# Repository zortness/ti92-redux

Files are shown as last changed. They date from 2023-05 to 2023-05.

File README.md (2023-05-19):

# TI-92 Redux
Bringing the TI-92's back to life.

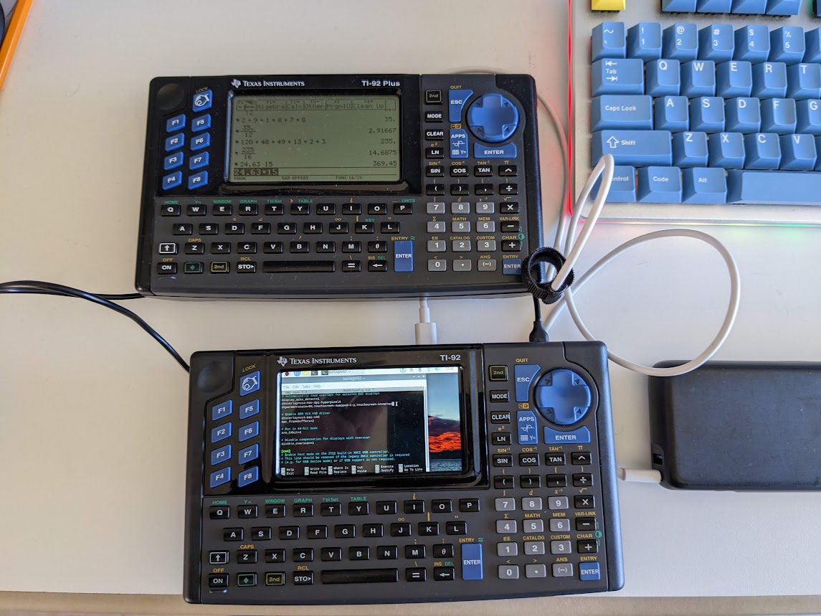
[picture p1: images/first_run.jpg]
First Run


## Intro
My first graphing calculator and introduction to portable programming was an early TI-85.
I became enamoured with the TI calculators in the 90s, longing for a TI-92 when they were
announced, but never able to purchase one. Now, you can find them in various conditions for
relatively cheap on the internet.

Unfortunately, the most common issues seem to be screen related, and the screens on the TI-92
are not easily repaired. Such was the case with one of the TI-92s I purchased, so I began 
thinking about how I could make use of this iconic chasis. 

I found other projects, notably one seen on Hackaday, the 
[TI-92 Revive project](https://hackaday.io/project/175448-reviving-the-ti-92-calculator-into-a-rpi-pc)
and corresponding [github repo](https://github.com/ccadic/TI92-revive). 
This is a cool project in a similar vein, but I wanted to make some different design decisions.

* First, I wanted the PCB to be as simple as possible for the first attempt, trying to keep to a 
2-layer board. 
* Second, I wanted to have the keyboard to be operable as a standalone unit, in case someone wanted
to use it on another project or different SBC than I chose.
* Third, I wanted to re-use as much of the original TI-92 chasis as possible. A goal which I didn't
meet to the original expectation due to the complexity of the original back plates. 

## Physical Replication Strategy
For several parts of this build, I traced the original components (PCB, back plate, etc) onto a 
piece of paper, then scanned them with a flat bed scanner. I then took the drawings and traced 
them into SVG's set to the correct dimensions using InkScape so I could use them with other tools 
such as KiCad and OpenSCAD. I also printed multiple versions of the PCB and various chasis bits 
on my 3D printer to work toward getting the correct fitment with the original chasis pieces.

Most of the SVGs and drawings are included [here](drawings/).

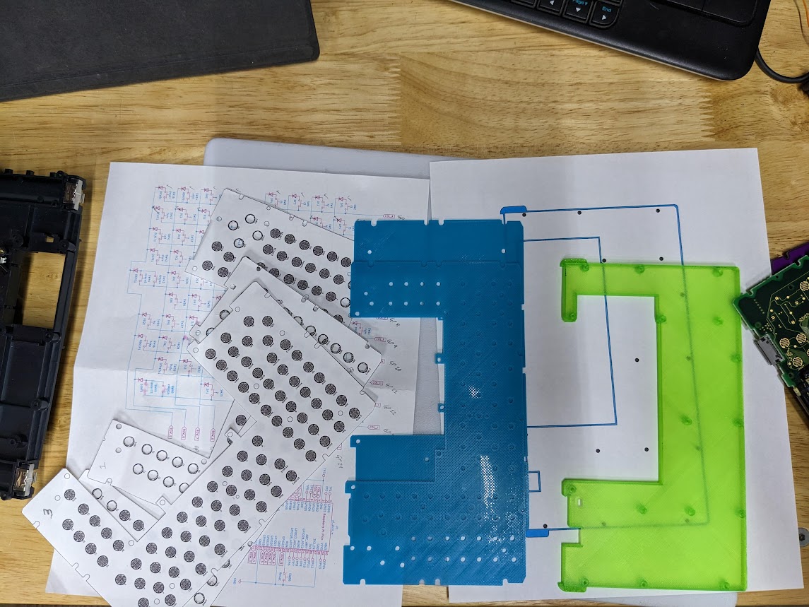
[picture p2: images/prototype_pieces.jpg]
prototypes


## PCB Design
The PCB is designed in KiCad 7. The board is designed as a custom keyboard, using a Pi Pico (or Pico W)
as the keybord controller. The routing is all done by hand with an attempt at keeping the jumps minimal.

Note: The PCB has tabs and holes to hold an SBC that lines up with the Raspberry Pi mounting holes.

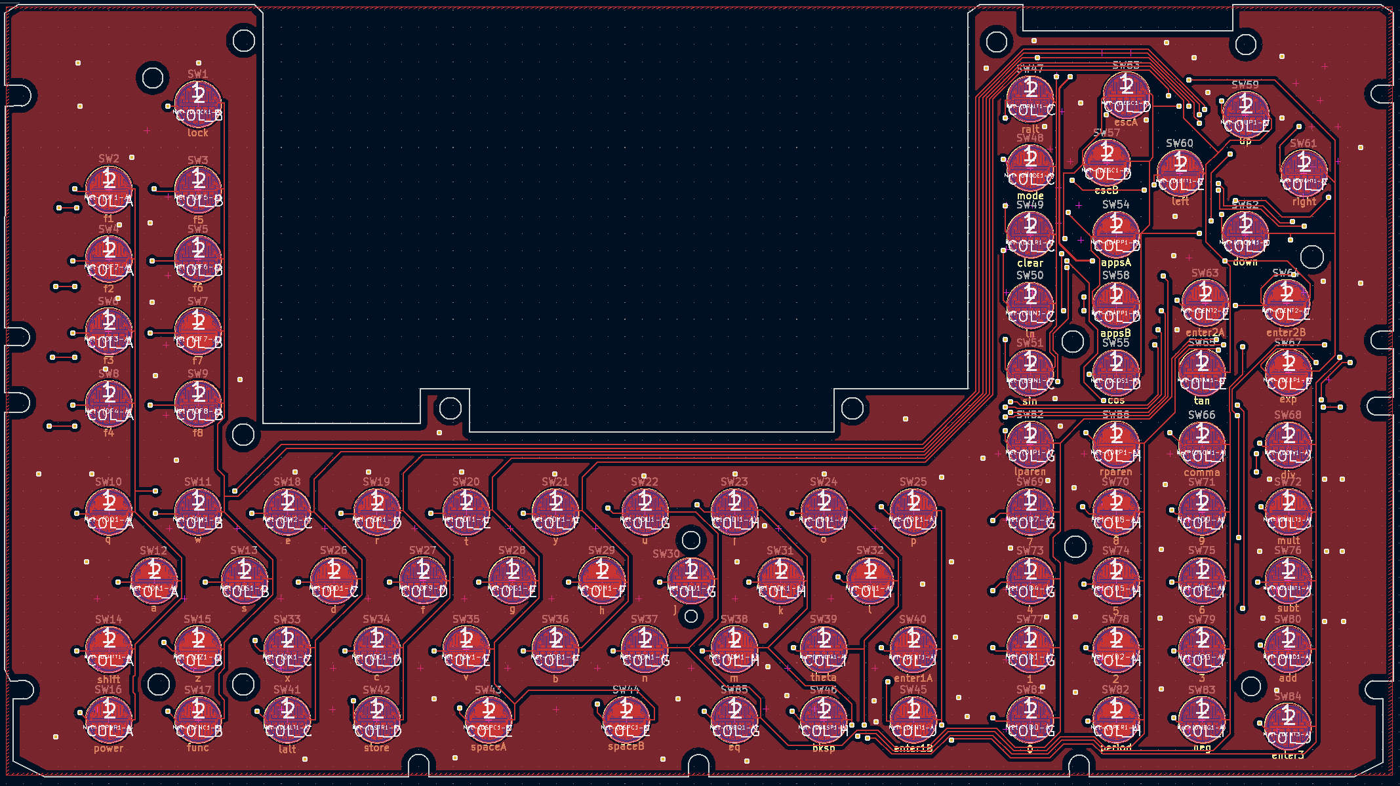
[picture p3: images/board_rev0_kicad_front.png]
Front

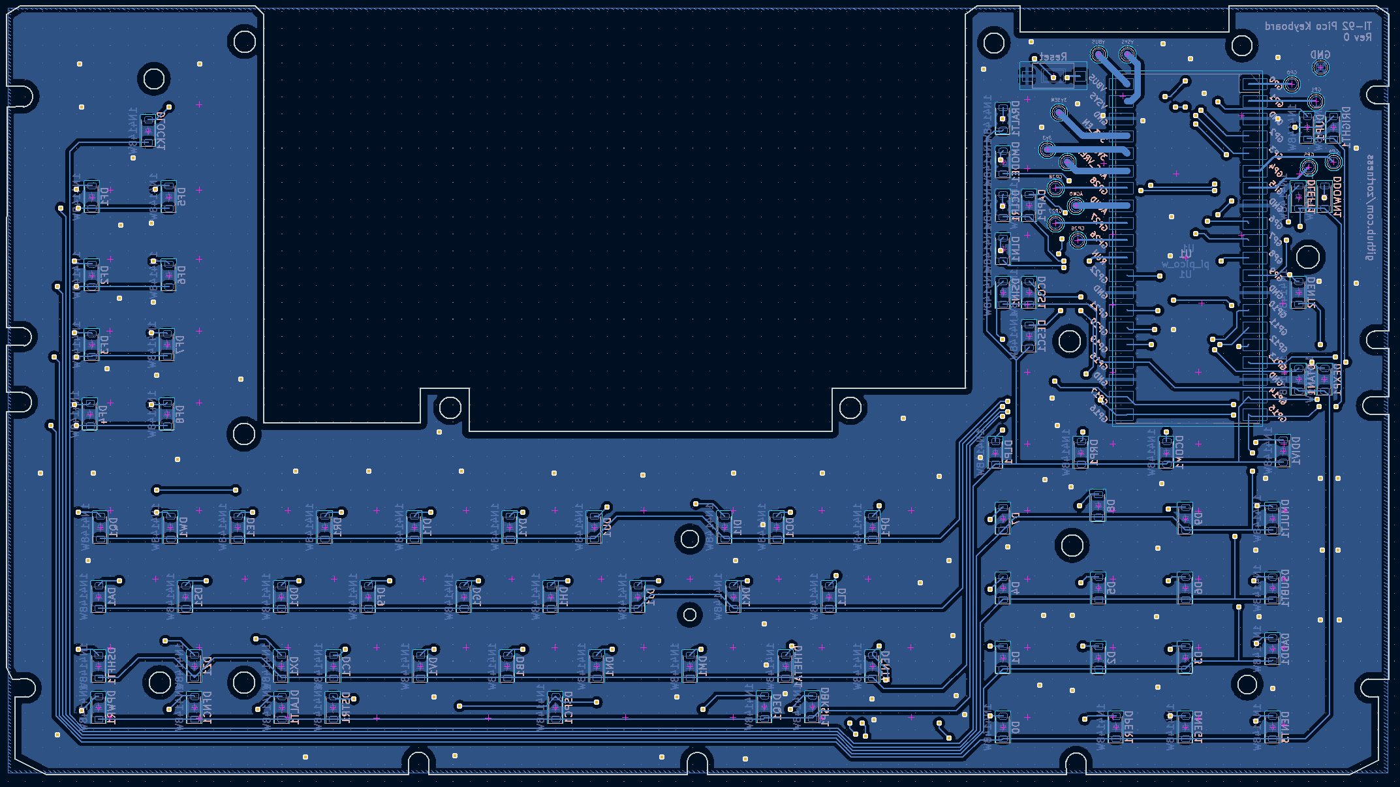
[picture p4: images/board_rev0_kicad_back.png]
Back

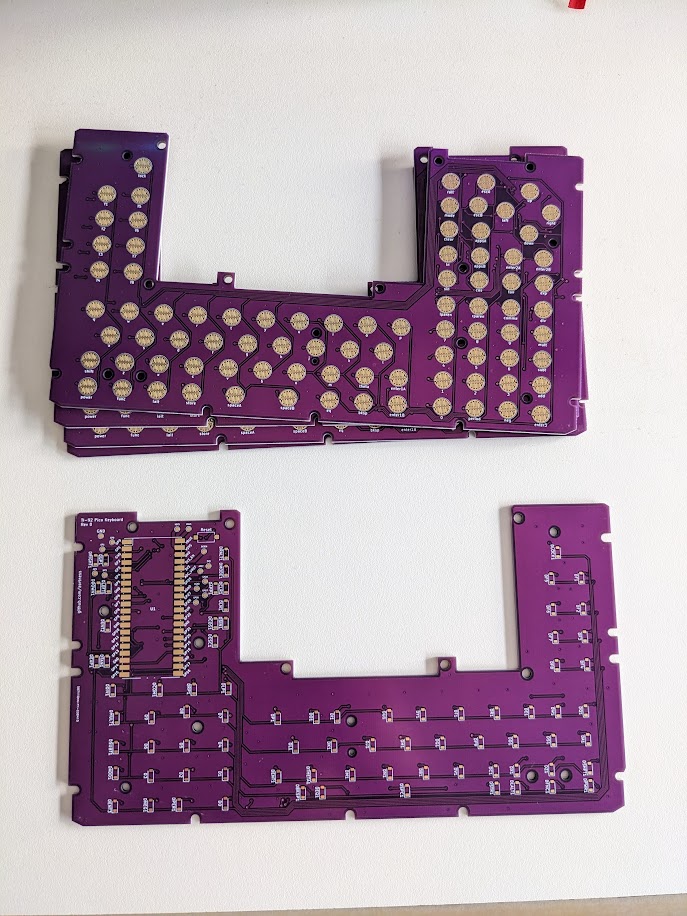
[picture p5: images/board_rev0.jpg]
Manufactured


### BOM And Assembly
* 80 count SOD-123 general purpose diode, [1N4148W-TP](https://www.digikey.com/en/products/detail/micro-commercial-co/1N4148W-TP/717196)
* 1 count [RS-282G05A3 tactile switch](https://www.digikey.com/en/products/detail/c-k/RS-282G05A3-SM-RT/2747190)
* 1 count [Pi Pico W](https://www.digikey.com/en/products/detail/raspberry-pi/SC0918/16608263)

I was able to solder all of this with a relatively large soldering iron and some tweezers.
Tin one of the pads for the component first, then heat it up again and set the part on the pad.
Only solder the second pad when you're happy with the alignment.

I used a Raspberry Pi 4 as my SBC.

To pair with the Pi 4, I used the [Pimoroni Hyperpixel 4.0" Touch Display](https://www.adafruit.com/product/3578).
This display is pretty expensive, but I purchased this a while ago, and noticing it seemed to fit perfectly
into the TI-92 chasis is one of the factors that pushed me into completing this project.

A 4" screen of this ratio fits almost perfectly into the TI-92. 

## Printed Pieces
I used OpenSCAD to assemble the designs for printing. Most of the prints are derived from one or 
more SVG drawings, the back plate being the most complicated.

During development, I dropped my keyboard and had to chase keys across the house multiple times. 
I ultimately ended up finding all of my keys, but there is a basic key file included in case you
need to print one.

## Keyboard Software
I chose the [KMK firmware](https://github.com/KMKfw/kmk_firmware) 
(as opposed to something like [QMK](https://docs.qmk.fm/#/) ) mostly due to ease of use and direct
support for the Pi Pico and Pico W. This has the added bonus of being able to easily reprogram the 
keyboard from the finished device itself, using the keyboard itself to make changes.

Follow the instructions for installing the KMK firmware on the device (basically copy most of the
files included in their release). Then drag and drop the [firmware/code.py](firmware/code.py) file
onto the device and it should be ready to go.

## Power Supply
There is no power supply built into this project. For my personal prototype, I'm using a 
[2x18650 container](https://www.digikey.com/en/products/detail/seeed-technology-co-ltd/114090053/10451921)
with a built-in on/off switch into a cheap buck converter. I also attempted to use a L7805 5V
linear regulator, and while it works, even with a heat sink it will get very hot.

I am currently powering the Pi Pico W through the USB cable that connects it to the Pi 4. 

## Development Software
* [KiCad 7](https://www.kicad.org/)
* [InkScape 1.2](https://inkscape.org/)
* [OpenSCAD](http://openscad.org/)
* [KMK Firmware](https://github.com/KMKfw/kmk_firmware)

## Version History

### 2023-05-19 Rev 0
* PCB Rev 0 - Functional 
  * Some mounting hole misalignments that need to be fixed by hand
* KMK Keyboard Firmware - Functional
  * Will work as a USB keyboard on any modern PC
  * Some QoL improvements need to be made on the mouse functionality
  * Really need BlueTooth support to eliminate the USB cable
* Back Plate - Functional
  * Very basic, you can tape or glue power sources to it if so inclined

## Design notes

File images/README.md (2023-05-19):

# TI-92 Redux Images

## Prototype Pieces
prototypes

## PCB Design
Front
Back

## Rev0 PCBs
Manufactured
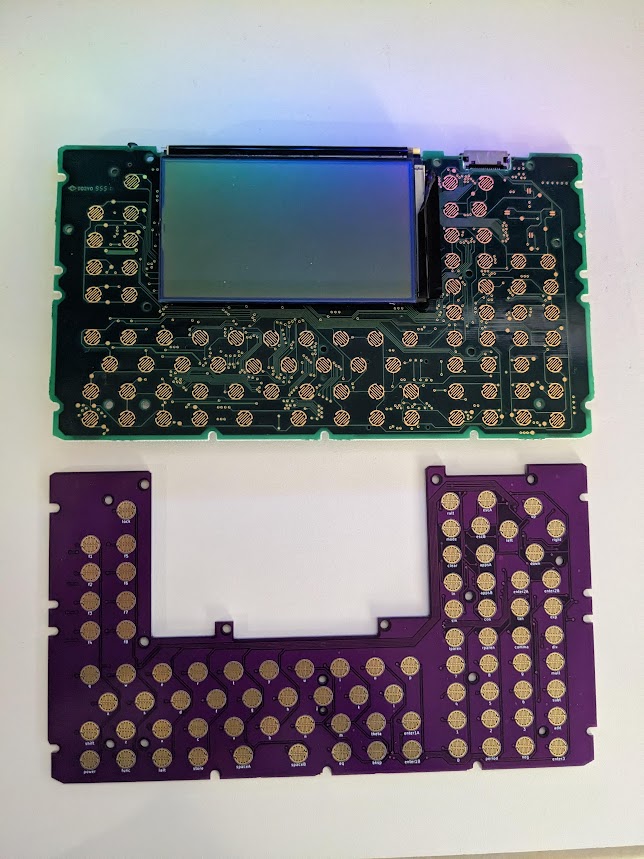
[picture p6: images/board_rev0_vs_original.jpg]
Manufactured vs Original

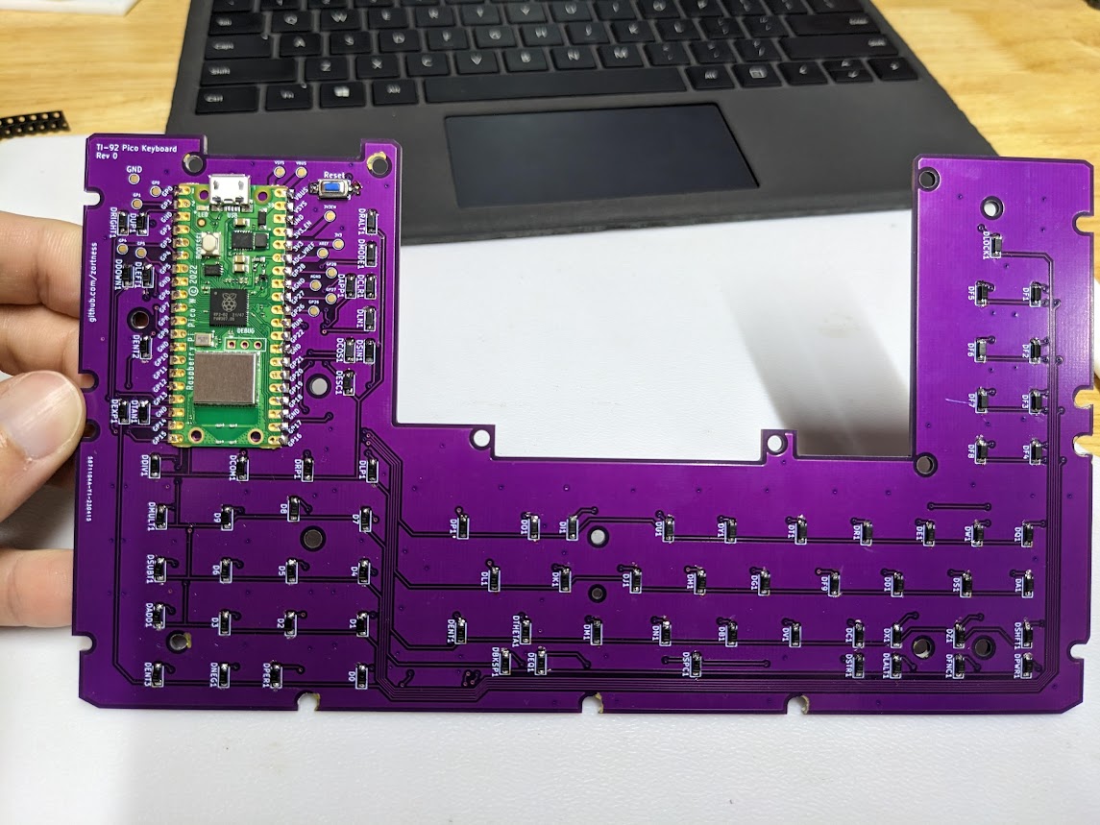
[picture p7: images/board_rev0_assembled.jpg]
Assembled


## Working!
First Run
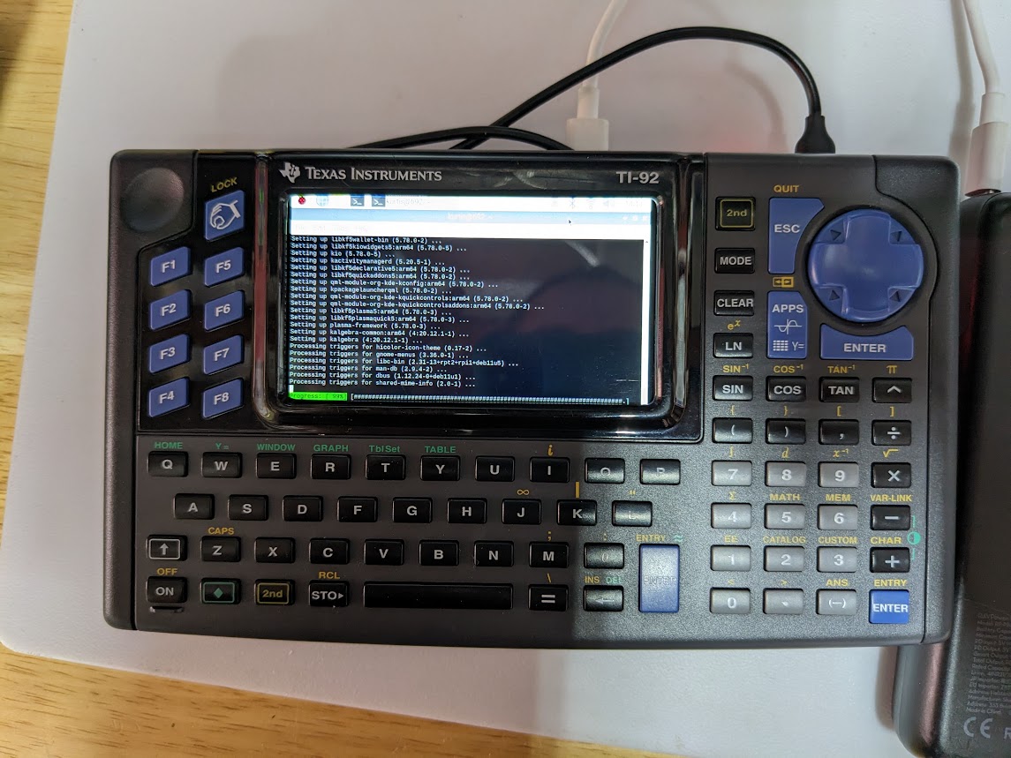
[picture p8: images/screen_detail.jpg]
Screen Detail

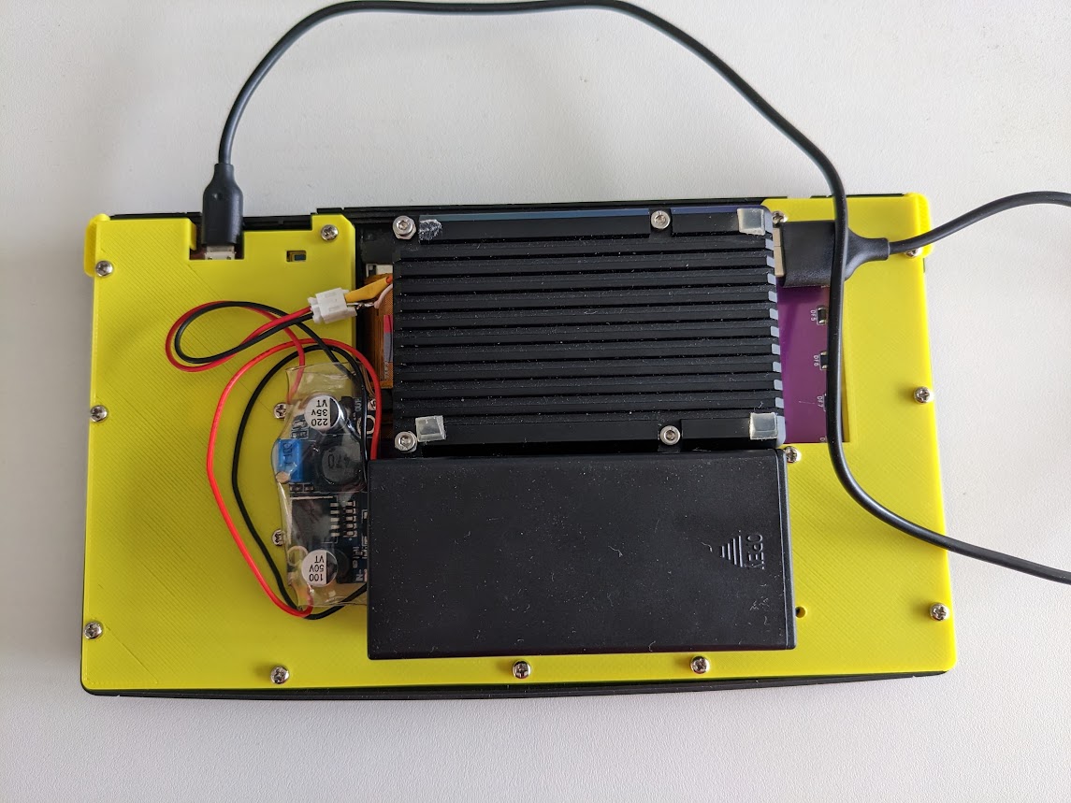
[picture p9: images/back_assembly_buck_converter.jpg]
Back Assembly


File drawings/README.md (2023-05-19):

# TI-92 Redux Drawings

I recommend using [InkScape](https://inkscape.org/) to view or modify these drawings.
Most of these were made directly with InkScape or exported from KiCad.

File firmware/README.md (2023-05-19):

# TI-92 Redux Keyboard Firmware

This firmware is based on the [KMK firmware](https://github.com/KMKfw/kmk_firmware).

Follow their instructions to install the KMK framework onto your Pi Pico or Pi Pico W,
then copy over the `code.py` file included here.

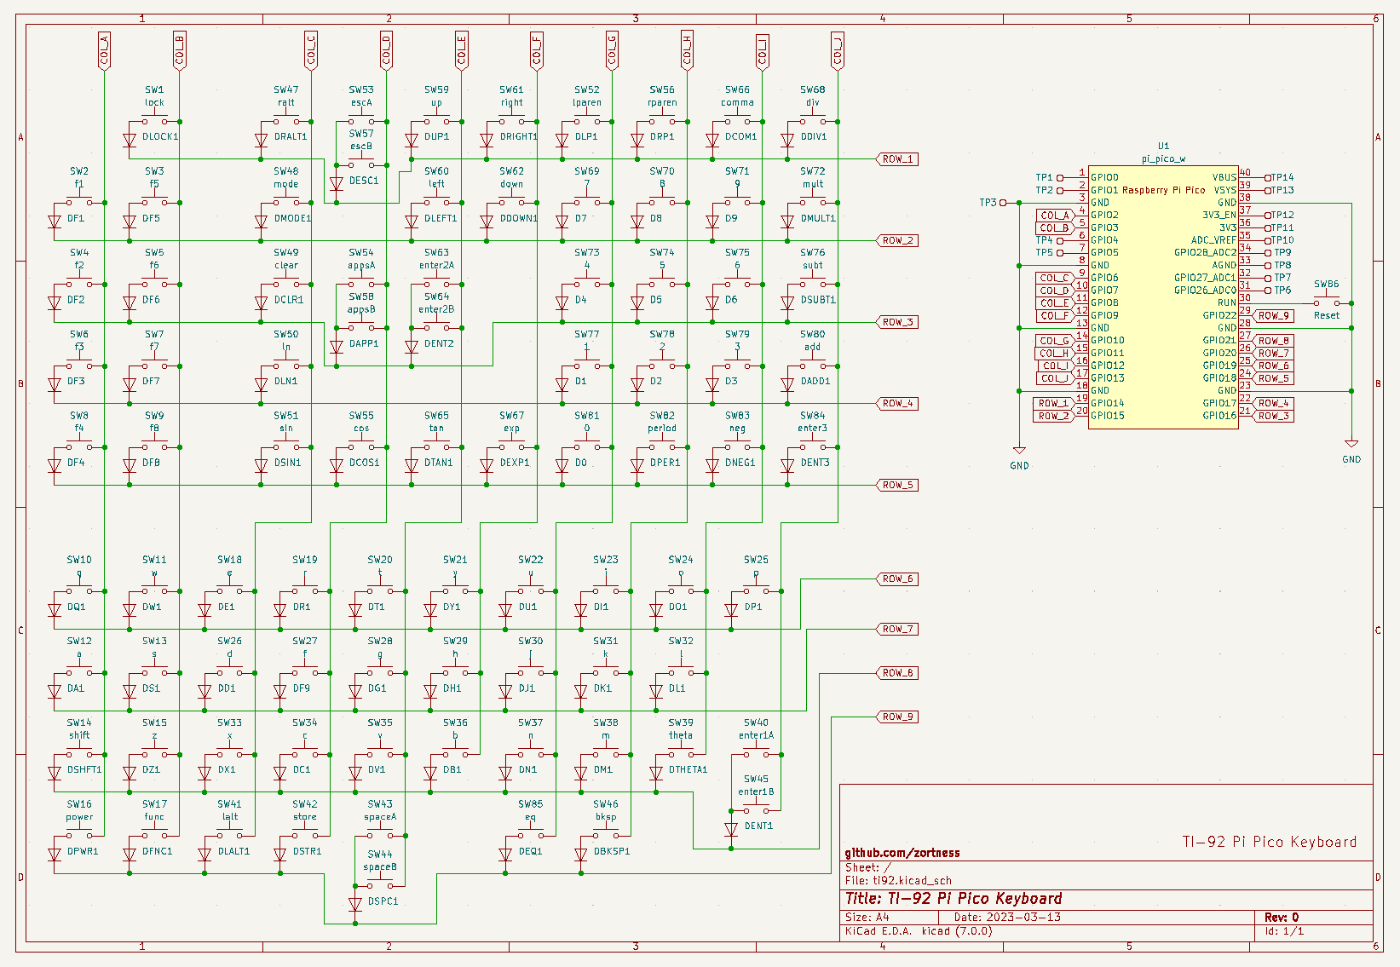
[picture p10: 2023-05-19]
images/board_rev0_kicad_schematic.png

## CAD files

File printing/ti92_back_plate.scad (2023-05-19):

$fn=96;


/**
* In newer releases of OpenSCAD we'll be able to specify
* layers that we want to import [feature added in 2022]
* import("ti92_back_drawing.svg", id="main_fill")
* id="outline"
* id="hole_casters"
* id="holes"
* But for now, we have each layer as its own file.
*/

height=5;
back_thickness=.6;
tab_thickness=3;

difference() {
    union() {
        translate([0,0,(height-back_thickness)])
        linear_extrude(back_thickness)
        import("../drawings/ti92_back_drawing.svg");
        
        linear_extrude(height)
        import("../drawings/ti92_back_drawing_outline.svg");
        
        linear_extrude(height)
        import("../drawings/ti92_back_drawing_hole_casters.svg");
    }
    
    
    // cut the holes
    translate([0,0,-0.01])
    linear_extrude(height+0.1)
    import("../drawings/ti92_back_drawing_holes.svg");
    
    // cut the USB cable slot
    #translate([54, 79, -0.01])
    linear_extrude(height-back_thickness)
    square([6,18]);
    
    // cut the reset button hole
    #translate([56, 105, 0])
    linear_extrude(height+0.1)
    square([3,5]);
    
    // cut the excess of the tabs
    #translate([43,52.9,tab_thickness])
    linear_extrude(height)
    square([20,5]);
    #translate([44.5,57,tab_thickness])
    linear_extrude(height)
    square([3,3]);
    
    #translate([43,260.8,tab_thickness])
    linear_extrude(height)
    square([20,5]);
    #translate([44.0,259,tab_thickness])
    linear_extrude(height)
    square([3,3]);
    
    // cut some diode interference holes where we took a chunk out for USB plugs on the right side
    #translate([62.5, 240, -0.01])
    linear_extrude(height/2)
    square([5,3]);
    
    #translate([106, 234, -0.01])
    linear_extrude(height/2)
    square([3,5]);
}

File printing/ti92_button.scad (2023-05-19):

$fn=96;



// base (mm)
baseWidth=10.54;
baseHeight=7.16;
baseDepth=2.08;

module baseChunk() {
    // this is naturally a top-right
    linear_extrude(height=baseDepth, scale=0.95)
    square([baseWidth/2,baseHeight/2]);
}

module drawBase() {
    // top right
    baseChunk();
    // top left
    mirror([1,0,0]) baseChunk();
    // bottom right
    mirror([0,1,0]) baseChunk();
    // bottom left
    rotate([0,0,180]) baseChunk();
}

drawBase();

upperWidth=9.22;
upperHeight=5.78;
upperDepth=4.90;

module upperChunk() {
    translate([0,0,baseDepth])
    linear_extrude(height=upperDepth, scale=0.95)
    square([upperWidth/2,upperHeight/2]);
}

module drawUpper() {
    // top right
    upperChunk();
    // top left
    mirror([1,0,0]) upperChunk();
    // bottom right
    mirror([0,1,0]) upperChunk();
    // bottom left
    rotate([0,0,180]) upperChunk();
}

drawUpper();

/*radius=5;
rotate([0,90,0])
translate([-radius,0,0])
linear_extrude(20)
circle(radius);
*/

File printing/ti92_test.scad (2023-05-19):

$fn=96;

difference() {
    
    // base rectangle
    translate([0,0,0.01])
    linear_extrude(0.6)
    square([202,112]);

    // cut away the edge layer
    linear_extrude(1)
    import("../drawings/ti92-brd.svg");

    // remove screen island
    translate([38.1,56.5,-0.01])
    linear_extrude(1.01)
    square([102,65]);
    
    translate([38.1,51.5,-0.01])
    linear_extrude(1.01)
    square([22.5,6]);
    
    translate([68,50,-0.01])
    linear_extrude(1.01)
    square([52.5,8]);
    
    //#translate([126.5,52.5,-0.01])
    //linear_extrude(1.01)
    //square([13.5,5]);
    
    // remove other little island
    translate([148.1,108.5,-0.01])
    linear_extrude(1.01)
    square([30.5,5]);
    
    // ** OUTER SCREWS **
    // LEFT EDGE
    /*
    #translate([2.5,12.8,-0.01])
    linear_extrude(1.01)
    circle(1.2);
    
    #translate([2.5,54.5,-0.01])
    linear_extrude(1.01)
    circle(1.2);
    
    #translate([2.5,64.1,-0.01])
    linear_extrude(1.01)
    circle(1.2);
    
    #translate([2.5,99.2,-0.01])
    linear_extrude(1.01)
    circle(1.2);
    
    // LOWER EDGE
    #translate([59,2,-0.01])
    linear_extrude(1.01)
    circle(1.2);
    
    #translate([100,2,-0.01])
    linear_extrude(1.01)
    circle(1.2);
    
    #translate([155.1,2,-0.01])
    linear_extrude(1.01)
    circle(1.2);
    */
}

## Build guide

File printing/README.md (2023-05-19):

# TI-92 Redux 3D Printing Files

These files require [OpenSCAD](http://openscad.org/).

I printed these files with an Ender 3 using PLA.

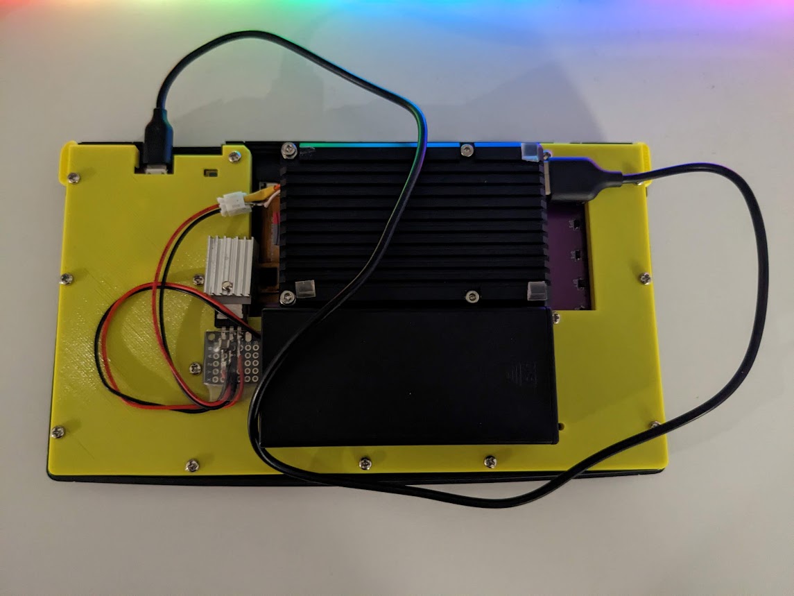
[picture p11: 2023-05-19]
images/back_assembly_linear_regulator.jpg

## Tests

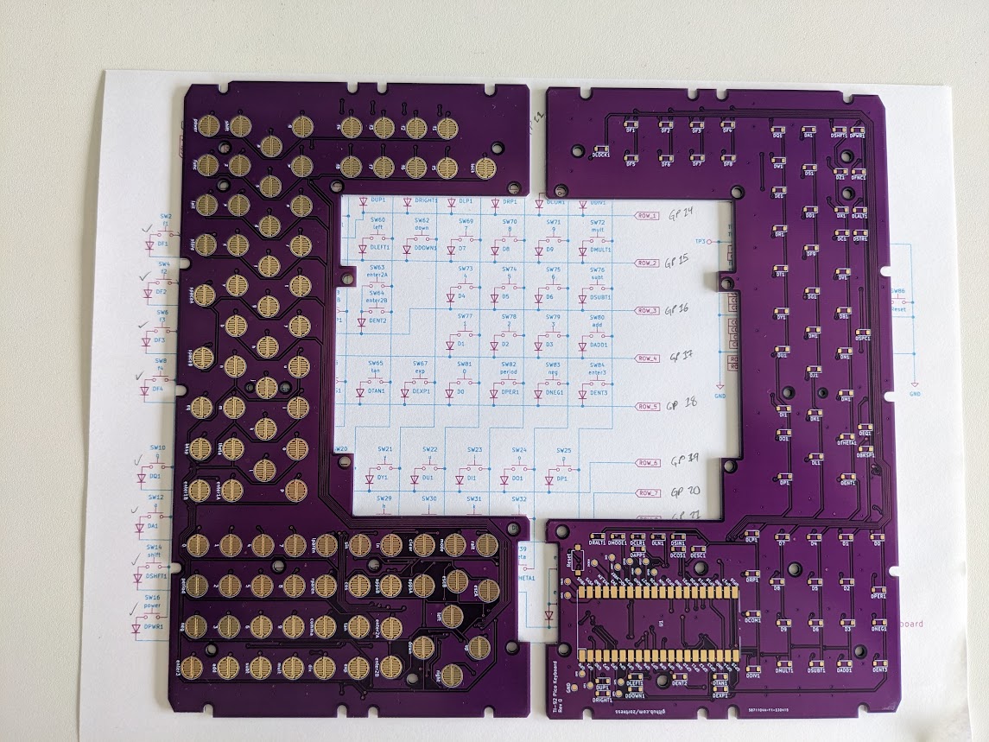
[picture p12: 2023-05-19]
images/board_rev0_pinout_testing.jpg

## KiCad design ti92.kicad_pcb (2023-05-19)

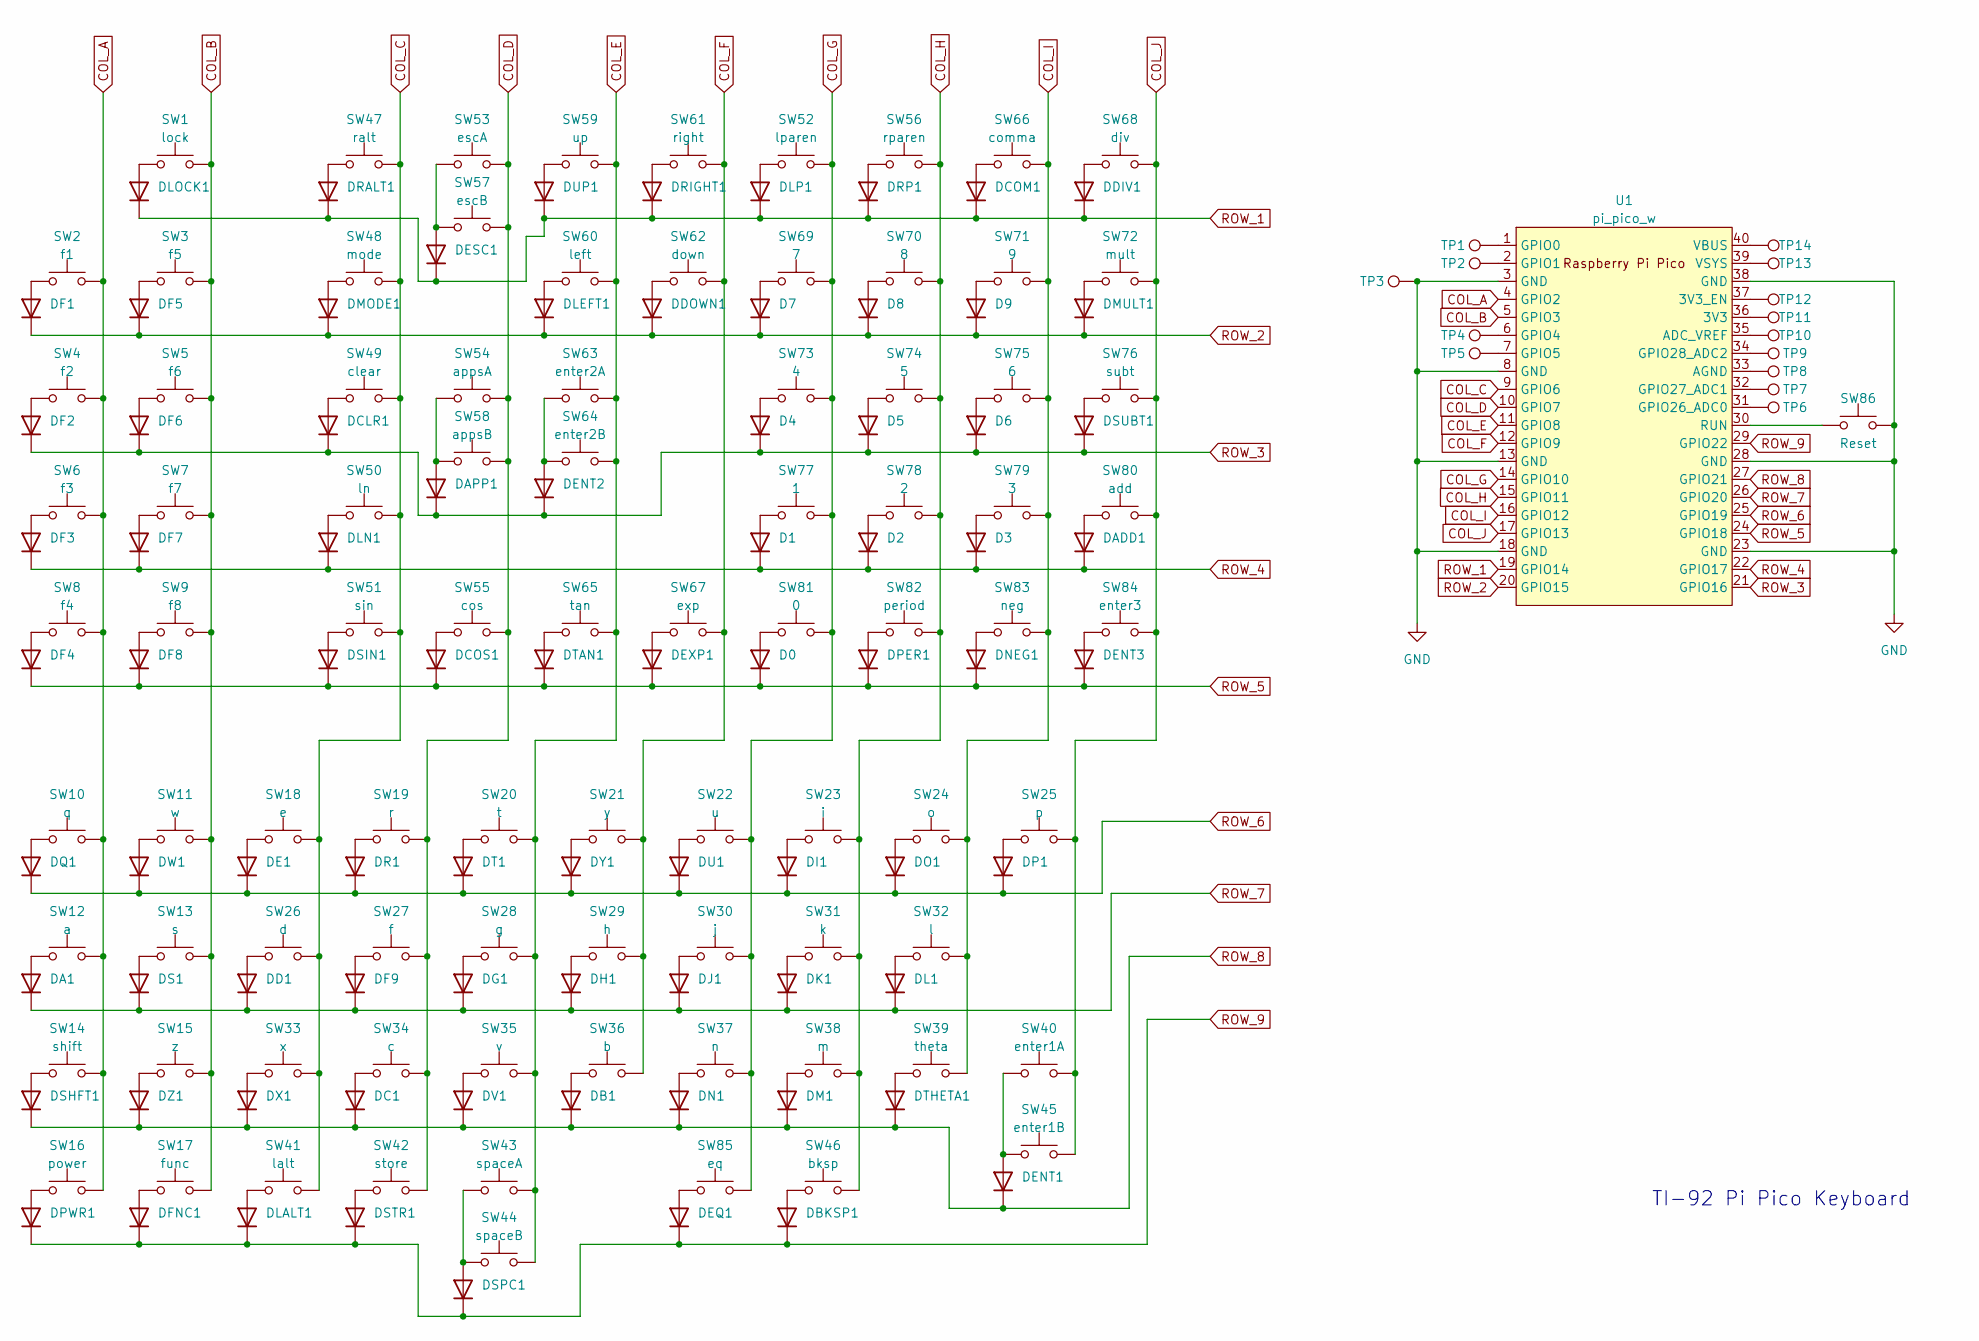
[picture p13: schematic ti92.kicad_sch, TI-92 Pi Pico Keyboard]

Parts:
D0, D1, D2, D3, D4, D5, D6, D7, D8, D9: 1N4148W; D_SOD-123
DA1: 1N4148W; D_SOD-123
DADD1: 1N4148W; D_SOD-123
DAPP1: 1N4148W; D_SOD-123
DB1: 1N4148W; D_SOD-123
DBKSP1: 1N4148W; D_SOD-123
DC1: 1N4148W; D_SOD-123
DCLR1: 1N4148W; D_SOD-123
DCOM1: 1N4148W; D_SOD-123
DCOS1: 1N4148W; D_SOD-123
DD1: 1N4148W; D_SOD-123
DDIV1: 1N4148W; D_SOD-123
DDOWN1: 1N4148W; D_SOD-123
DE1: 1N4148W; D_SOD-123
DENT1, DENT2, DENT3: 1N4148W; D_SOD-123
DEQ1: 1N4148W; D_SOD-123
DESC1: 1N4148W; D_SOD-123
DEXP1: 1N4148W; D_SOD-123
DF1, DF2, DF3, DF4, DF5, DF6, DF7, DF8, DF9: 1N4148W; D_SOD-123
DFNC1: 1N4148W; D_SOD-123
DG1: 1N4148W; D_SOD-123
DH1: 1N4148W; D_SOD-123
DI1: 1N4148W; D_SOD-123
DJ1: 1N4148W; D_SOD-123
DK1: 1N4148W; D_SOD-123
DL1: 1N4148W; D_SOD-123
DLALT1: 1N4148W; D_SOD-123
DLEFT1: 1N4148W; D_SOD-123
DLN1: 1N4148W; D_SOD-123
DLOCK1: 1N4148W; D_SOD-123
DLP1: 1N4148W; D_SOD-123
DM1: 1N4148W; D_SOD-123
DMODE1: 1N4148W; D_SOD-123
DMULT1: 1N4148W; D_SOD-123
DN1: 1N4148W; D_SOD-123
DNEG1: 1N4148W; D_SOD-123
DO1: 1N4148W; D_SOD-123
DP1: 1N4148W; D_SOD-123
DPER1: 1N4148W; D_SOD-123
DPWR1: 1N4148W; D_SOD-123
DQ1: 1N4148W; D_SOD-123
DR1: 1N4148W; D_SOD-123
DRALT1: 1N4148W; D_SOD-123
DRIGHT1: 1N4148W; D_SOD-123
DRP1: 1N4148W; D_SOD-123
DS1: 1N4148W; D_SOD-123
DSHFT1: 1N4148W; D_SOD-123
DSIN1: 1N4148W; D_SOD-123
DSPC1: 1N4148W; D_SOD-123
DSTR1: 1N4148W; D_SOD-123
DSUBT1: 1N4148W; D_SOD-123
DT1: 1N4148W; D_SOD-123
DTAN1: 1N4148W; D_SOD-123
DTHETA1: 1N4148W; D_SOD-123
DU1: 1N4148W; D_SOD-123
DUP1: 1N4148W; D_SOD-123
DV1: 1N4148W; D_SOD-123
DW1: 1N4148W; D_SOD-123
DX1: 1N4148W; D_SOD-123
DY1: 1N4148W; D_SOD-123
DZ1: 1N4148W; D_SOD-123
SW1: lock; tibuttonpad
SW2: f1; tibuttonpad
SW3: f5; tibuttonpad
SW4: f2; tibuttonpad
SW5: f6; tibuttonpad
SW6: f3; tibuttonpad
SW7: f7; tibuttonpad
SW8: f4; tibuttonpad
SW9: f8; tibuttonpad
SW10: q; tibuttonpad
SW11: w; tibuttonpad
SW12: a; tibuttonpad
SW13: s; tibuttonpad
SW14: shift; tibuttonpad
SW15: z; tibuttonpad
SW16: power; tibuttonpad
SW17: func; tibuttonpad
SW18: e; tibuttonpad
SW19: r; tibuttonpad
SW20: t; tibuttonpad
SW21: y; tibuttonpad
SW22: u; tibuttonpad
SW23: i; tibuttonpad
SW24: o; tibuttonpad
SW25: p; tibuttonpad
SW26: d; tibuttonpad
SW27: f; tibuttonpad
SW28: g; tibuttonpad
SW29: h; tibuttonpad
SW30: j; tibuttonpad
SW31: k; tibuttonpad
SW32: l; tibuttonpad
SW33: x; tibuttonpad
SW34: c; tibuttonpad
SW35: v; tibuttonpad
SW36: b; tibuttonpad
SW37: n; tibuttonpad
SW38: m; tibuttonpad
SW39: theta; tibuttonpad
SW40: enter1A; tibuttonpad
SW41: lalt; tibuttonpad
SW42: store; tibuttonpad
SW43: spaceA; tibuttonpad
SW44: spaceB; tibuttonpad
SW45: enter1B; tibuttonpad
SW46: bksp; tibuttonpad
SW47: ralt; tibuttonpad
SW48: mode; tibuttonpad
SW49: clear; tibuttonpad
SW50: ln; tibuttonpad
SW51: sin; tibuttonpad
SW52: lparen; tibuttonpad
SW53: escA; tibuttonpad
SW54: appsA; tibuttonpad
SW55: cos; tibuttonpad
SW56: rparen; tibuttonpad
SW57: escB; tibuttonpad
SW58: appsB; tibuttonpad
SW59: up; tibuttonpad
SW60: left; tibuttonpad
SW61: right; tibuttonpad
SW62: down; tibuttonpad
SW63: enter2A; tibuttonpad
SW64: enter2B; tibuttonpad
SW65: tan; tibuttonpad
SW66: comma; tibuttonpad
SW67: exp; tibuttonpad
SW68: div; tibuttonpad
SW69: 7; tibuttonpad
SW70: 8; tibuttonpad
SW71: 9; tibuttonpad
SW72: mult; tibuttonpad
SW73: 4; tibuttonpad
SW74: 5; tibuttonpad
SW75: 6; tibuttonpad
SW76: subt; tibuttonpad
SW77: 1; tibuttonpad
SW78: 2; tibuttonpad
SW79: 3; tibuttonpad
SW80: add; tibuttonpad
SW81: 0; tibuttonpad
SW82: period; tibuttonpad
SW83: neg; tibuttonpad
SW84: enter3; tibuttonpad
SW85: eq; tibuttonpad
SW86: Reset; SW_SPST_CK_RS282G05A3
TP1, TP2, TP3, TP4, TP5, TP6, TP7, TP8, TP9, TP10, TP11, TP12, TP13, TP14: TestPoint_Pad_D1.5mm
U1: pi_pico_w

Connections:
COL_A: SW2.2, SW4.2, SW6.2, SW8.2, SW10.2, SW12.2, SW14.2, SW16.2, U1.4 (GPIO2)
COL_B: SW1.2, SW3.2, SW5.2, SW7.2, SW9.2, SW11.2, SW13.2, SW15.2, SW17.2, U1.5 (GPIO3)
COL_C: SW18.2, SW26.2, SW33.2, SW41.2, SW47.2, SW48.2, SW49.2, SW50.2, SW51.2, U1.9 (GPIO6)
COL_D: SW19.2, SW27.2, SW34.2, SW42.2, SW53.2, SW54.2, SW55.2, SW57.2, SW58.2, U1.10 (GPIO7)
COL_E: SW20.2, SW28.2, SW35.2, SW43.2, SW44.2, SW59.2, SW60.2, SW63.2, SW64.2, SW65.2, U1.11 (GPIO8)
COL_F: SW21.2, SW29.2, SW36.2, SW61.2, SW62.2, SW67.2, U1.12 (GPIO9)
COL_G: SW22.2, SW30.2, SW37.2, SW52.2, SW69.2, SW73.2, SW77.2, SW81.2, SW85.2, U1.14 (GPIO10)
COL_H: SW23.2, SW31.2, SW38.2, SW46.2, SW56.2, SW70.2, SW74.2, SW78.2, SW82.2, U1.15 (GPIO11)
COL_I: SW24.2, SW32.2, SW39.2, SW66.2, SW71.2, SW75.2, SW79.2, SW83.2, U1.16 (GPIO12)
COL_J: SW25.2, SW40.2, SW45.2, SW68.2, SW72.2, SW76.2, SW80.2, SW84.2, U1.17 (GPIO13)
GND: SW86.2, TP3.1, U1.3 (GND), U1.8 (GND), U1.13 (GND), U1.18 (GND), U1.23 (GND), U1.28 (GND), U1.38 (GND)
unnamed: D0.2 (A), SW81.1
unnamed: D1.2 (A), SW77.1
unnamed: D2.2 (A), SW78.1
unnamed: D3.2 (A), SW79.1
unnamed: D4.2 (A), SW73.1
unnamed: D5.2 (A), SW74.1
unnamed: D6.2 (A), SW75.1
unnamed: D7.2 (A), SW69.1
unnamed: D8.2 (A), SW70.1
unnamed: D9.2 (A), SW71.1
unnamed: DA1.2 (A), SW12.1
unnamed: DADD1.2 (A), SW80.1
unnamed: DAPP1.2 (A), SW54.1, SW58.1
unnamed: DB1.2 (A), SW36.1
unnamed: DBKSP1.2 (A), SW46.1
unnamed: DC1.2 (A), SW34.1
unnamed: DCLR1.2 (A), SW49.1
unnamed: DCOM1.2 (A), SW66.1
unnamed: DCOS1.2 (A), SW55.1
unnamed: DD1.2 (A), SW26.1
unnamed: DDIV1.2 (A), SW68.1
unnamed: DDOWN1.2 (A), SW62.1
unnamed: DENT1.2 (A), SW40.1, SW45.1
unnamed: DENT2.2 (A), SW63.1, SW64.1
unnamed: DENT3.2 (A), SW84.1
unnamed: DEQ1.2 (A), SW85.1
unnamed: DESC1.2 (A), SW53.1, SW57.1
unnamed: DEXP1.2 (A), SW67.1
unnamed: DF1.2 (A), SW2.1
unnamed: DF2.2 (A), SW4.1
unnamed: DF3.2 (A), SW6.1
unnamed: DF4.2 (A), SW8.1
unnamed: DF5.2 (A), SW3.1
unnamed: DF6.2 (A), SW5.1
unnamed: DF7.2 (A), SW7.1
unnamed: DF8.2 (A), SW9.1
unnamed: DF9.2 (A), SW27.1
unnamed: DFNC1.2 (A), SW17.1
unnamed: DG1.2 (A), SW28.1
unnamed: DH1.2 (A), SW29.1
unnamed: DI1.2 (A), SW23.1
unnamed: DJ1.2 (A), SW30.1
unnamed: DK1.2 (A), SW31.1
unnamed: DL1.2 (A), SW32.1
unnamed: DLALT1.2 (A), SW41.1
unnamed: DLEFT1.2 (A), SW60.1
unnamed: DLN1.2 (A), SW50.1
unnamed: DLOCK1.2 (A), SW1.1
unnamed: DLP1.2 (A), SW52.1
unnamed: DM1.2 (A), SW38.1
unnamed: DMODE1.2 (A), SW48.1
unnamed: DMULT1.2 (A), SW72.1
unnamed: DN1.2 (A), SW37.1
unnamed: DNEG1.2 (A), SW83.1
unnamed: DO1.2 (A), SW24.1
unnamed: DP1.2 (A), SW25.1
unnamed: DPER1.2 (A), SW82.1
unnamed: DPWR1.2 (A), SW16.1
unnamed: DQ1.2 (A), SW10.1
unnamed: DR1.2 (A), SW19.1
unnamed: DRALT1.2 (A), SW47.1
unnamed: DRIGHT1.2 (A), SW61.1
unnamed: DRP1.2 (A), SW56.1
unnamed: DS1.2 (A), SW13.1
unnamed: DSHFT1.2 (A), SW14.1
unnamed: DSIN1.2 (A), SW51.1
unnamed: DSPC1.2 (A), SW43.1, SW44.1
unnamed: DSTR1.2 (A), SW42.1
unnamed: DSUBT1.2 (A), SW76.1
unnamed: DT1.2 (A), SW20.1
unnamed: DTAN1.2 (A), SW65.1
unnamed: DTHETA1.2 (A), SW39.1
unnamed: DU1.2 (A), SW22.1
unnamed: DUP1.2 (A), SW59.1
unnamed: DV1.2 (A), SW35.1
unnamed: DW1.2 (A), SW11.1
unnamed: DE1.2 (A), SW18.1
unnamed: DX1.2 (A), SW33.1
unnamed: DY1.2 (A), SW21.1
unnamed: DZ1.2 (A), SW15.1
unnamed: TP11.1, U1.36 (3V3)
unnamed: TP12.1, U1.37 (3V3_EN)
unnamed: TP10.1, U1.35 (ADC_VREF)
unnamed: TP8.1, U1.33 (AGND)
unnamed: TP1.1, U1.1 (GPIO0)
unnamed: TP2.1, U1.2 (GPIO1)
unnamed: TP4.1, U1.6 (GPIO4)
unnamed: TP5.1, U1.7 (GPIO5)
unnamed: TP6.1, U1.31 (GPIO26_ADC0)
unnamed: TP7.1, U1.32 (GPIO27_ADC1)
unnamed: TP9.1, U1.34 (GPIO28_ADC2)
unnamed: SW86.1, U1.30 (RUN)
unnamed: TP14.1, U1.40 (VBUS)
unnamed: TP13.1, U1.39 (VSYS)
ROW_1: DCOM1.1 (K), DDIV1.1 (K), DESC1.1 (K), DLOCK1.1 (K), DLP1.1 (K), DRALT1.1 (K), DRIGHT1.1 (K), DRP1.1 (K), DUP1.1 (K), U1.19 (GPIO14)
ROW_2: D7.1 (K), D8.1 (K), D9.1 (K), DDOWN1.1 (K), DF1.1 (K), DF5.1 (K), DLEFT1.1 (K), DMODE1.1 (K), DMULT1.1 (K), U1.20 (GPIO15)
ROW_3: D4.1 (K), D5.1 (K), D6.1 (K), DAPP1.1 (K), DCLR1.1 (K), DENT2.1 (K), DF2.1 (K), DF6.1 (K), DSUBT1.1 (K), U1.21 (GPIO16)
ROW_4: D1.1 (K), D2.1 (K), D3.1 (K), DADD1.1 (K), DF3.1 (K), DF7.1 (K), DLN1.1 (K), U1.22 (GPIO17)
ROW_5: D0.1 (K), DCOS1.1 (K), DENT3.1 (K), DEXP1.1 (K), DF4.1 (K), DF8.1 (K), DNEG1.1 (K), DPER1.1 (K), DSIN1.1 (K), DTAN1.1 (K), U1.24 (GPIO18)
ROW_6: DE1.1 (K), DI1.1 (K), DO1.1 (K), DP1.1 (K), DQ1.1 (K), DR1.1 (K), DT1.1 (K), DU1.1 (K), DW1.1 (K), DY1.1 (K), U1.25 (GPIO19)
ROW_7: DA1.1 (K), DD1.1 (K), DF9.1 (K), DG1.1 (K), DH1.1 (K), DJ1.1 (K), DK1.1 (K), DL1.1 (K), DS1.1 (K), U1.26 (GPIO20)
ROW_8: DB1.1 (K), DC1.1 (K), DENT1.1 (K), DM1.1 (K), DN1.1 (K), DSHFT1.1 (K), DTHETA1.1 (K), DV1.1 (K), DX1.1 (K), DZ1.1 (K), U1.27 (GPIO21)
ROW_9: DBKSP1.1 (K), DEQ1.1 (K), DFNC1.1 (K), DLALT1.1 (K), DPWR1.1 (K), DSPC1.1 (K), DSTR1.1 (K), U1.29 (GPIO22)

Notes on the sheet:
TI-92 Pi Pico Keyboard

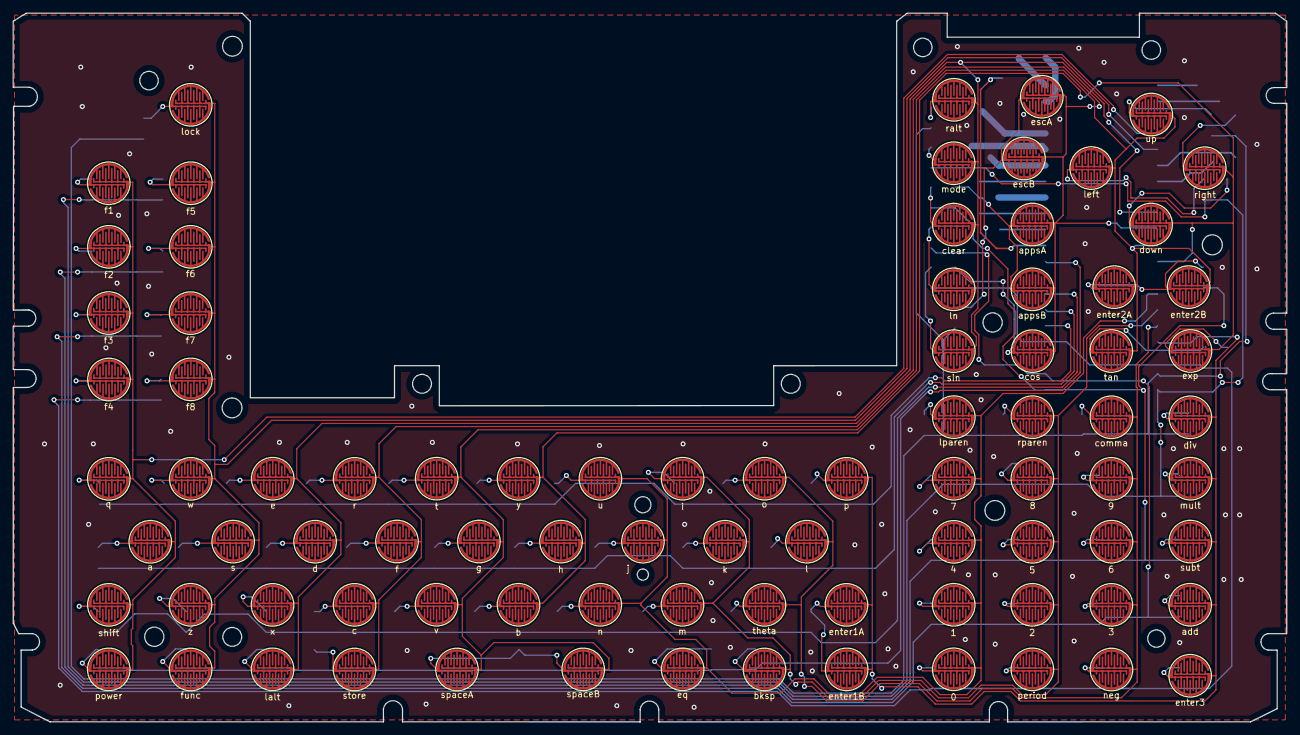
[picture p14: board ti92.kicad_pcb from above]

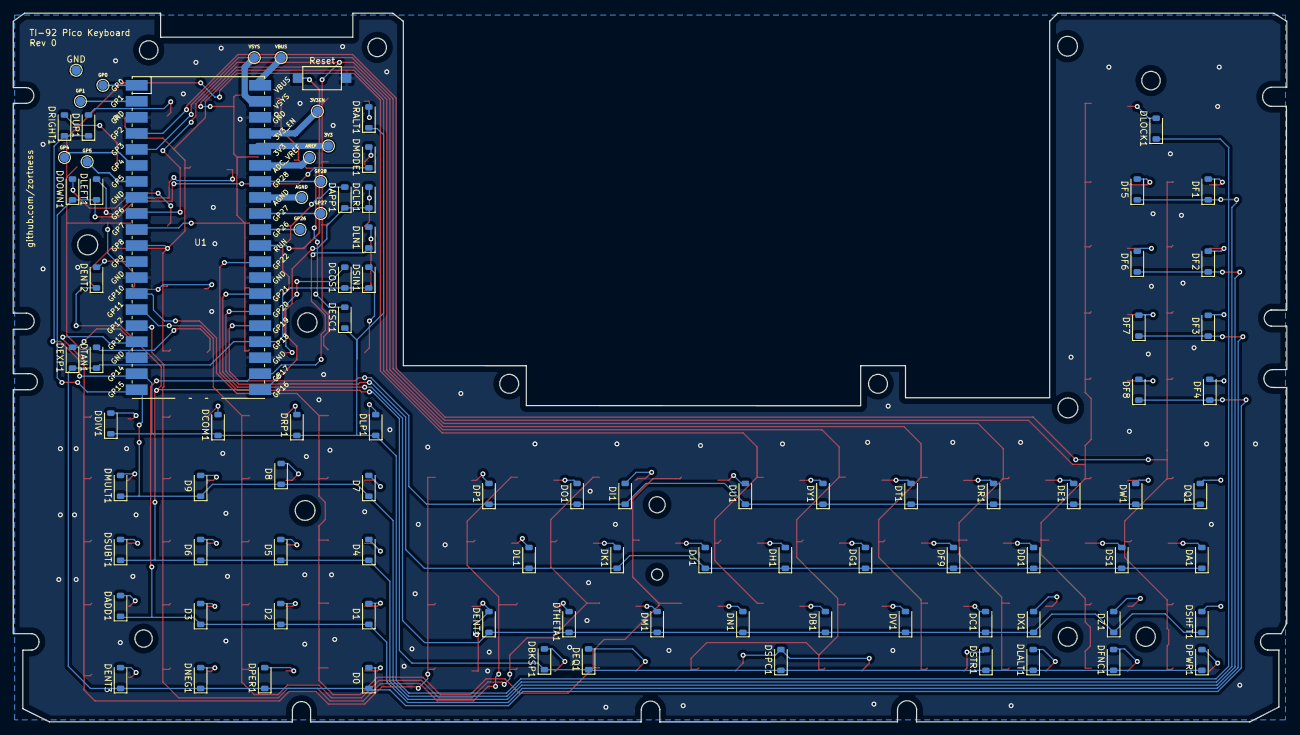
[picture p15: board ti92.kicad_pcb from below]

Board: 2 copper layers, 201.9 x 112.4 mm, 181 parts (96 on the bottom side), 114 nets.

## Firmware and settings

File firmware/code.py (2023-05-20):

print("Starting")

import board

from kmk.kmk_keyboard import KMKKeyboard
from kmk.keys import KC
from kmk.scanners import DiodeOrientation
from kmk.modules.layers import Layers
from kmk.handlers.sequences import unicode_codepoint_sequence
from kmk.handlers.sequences import send_string
from kmk.handlers.sequences import simple_key_sequence
from kmk.modules.mouse_keys import MouseKeys
from kmk.extensions.media_keys import MediaKeys

keyboard = KMKKeyboard()

keyboard.modules.append(Layers())
keyboard.modules.append(MouseKeys())
keyboard.extensions.append(MediaKeys())

keyboard.col_pins = (board.GP2, board.GP3, board.GP6, board.GP7, board.GP8, board.GP9, board.GP10, board.GP11, board.GP12, board.GP13)
keyboard.row_pins = (board.GP14, board.GP15, board.GP16, board.GP17, board.GP18, board.GP19, board.GP20, board.GP21, board.GP22)
keyboard.diode_orientation = DiodeOrientation.COL2ROW

# custom keys
______ = KC.NO
KC_SQRT = unicode_codepoint_sequence(["221a"]) # square root symbol
KC_PI = unicode_codepoint_sequence(["03c0"]) # pi symbol
KC_SUM = unicode_codepoint_sequence(["2140"]) # summation symbol
KC_INF = unicode_codepoint_sequence(["221e"]) # infinity
KC_INT = unicode_codepoint_sequence(["222b"]) # integral
KC_EX = unicode_codepoint_sequence(["0065","1d61"]) # e^x
KC_LN = send_string("LN") # LN
KC_SIN = send_string("SIN") # SIN
KC_COS = send_string("COS") # COS
KC_TAN = send_string("TAN") # TAN
KC_THTA = unicode_codepoint_sequence(["03b8"]) # theta
KC_PWR = unicode_codepoint_sequence(["23fb"]) # power
KC_NXT = simple_key_sequence(
    (
        KC.LALT(no_release=True), 
        KC.MACRO_SLEEP_MS(30),
        KC.TAB,
        KC.MACRO_SLEEP_MS(30),
        KC.LALT(no_press=True),
    )
)

# layer keys
MOUSE_EN = KC.MO(1)
MOUSE_TG = KC.TG(1)
SEC_EN = KC.MO(2)
DIA_EN = KC.MO(3)


keyboard.keymap = [
    [ # Layer 0
        ______,  MOUSE_EN, SEC_EN,   KC.ESC,  KC.UP,   KC.RIGHT, KC.LPRN, KC.RPRN, KC.COMMA, KC.SLASH,
        KC.F1,   KC.F5,    KC.LCTRL, ______,  KC.LEFT, KC.DOWN,  KC.N7,   KC.N8,   KC.N9,    KC.ASTERISK,
        KC.F2,   KC.F6,    KC.DEL,   KC.LGUI, KC.ENT,  ______,   KC.N4,   KC.N5,   KC.N6,    KC.MINUS,
        KC.F3,   KC.F7,    KC_LN,    ______,  ______,  ______,   KC.N1,   KC.N2,   KC.N3,    KC.PLUS,
        KC.F4,   KC.F8,    KC_SIN,   KC_COS,  KC_TAN,  KC.CIRC,  KC.N0,   KC.DOT,  KC.MINUS, KC.ENT,
        KC.Q,    KC.W,     KC.E,     KC.R,    KC.T,    KC.Y,     KC.U,    KC.I,    KC.O,     KC.P,
        KC.A,    KC.S,     KC.D,     KC.F,    KC.G,    KC.H,     KC.J,    KC.K,    KC.L,     ______,
        KC.LSFT, KC.Z,     KC.X,     KC.C,    KC.V,    KC.B,     KC.N,    KC.M,    KC_THTA,  KC.ENT,
        KC.LALT,  DIA_EN,   SEC_EN,   KC.TAB,  KC.SPC,  ______,   KC.EQL,  KC.BSPC, ______,   ______,
    ],
    [ # Layer 1 (mouse)
        ______,  ______,   SEC_EN,   KC.ESC,    KC.MS_UP,  KC.MS_RT, KC.LPRN, KC.RPRN, KC.COMMA, KC.SLASH,
        KC.F1,   KC.F5,    KC.LCTRL, ______,    KC.MS_LT,  KC.MS_DN, KC.N7,   KC.N8,   KC.N9,    KC.ASTERISK,
        KC.F2,   KC.F6,    KC.DEL,   KC.MB_LMB, KC.MB_RMB, ______,   KC.N4,   KC.N5,   KC.N6,    KC.MINUS,
        KC.F3,   KC.F7,    KC_LN,    ______,    ______,    ______,   KC.N1,   KC.N2,   KC.N3,    KC.PLUS,
        KC.F4,   KC.F8,    KC_SIN,   KC_COS,    KC_TAN,    KC.CIRC,  KC.N0,   KC.DOT,  KC.MINUS, KC.ENT,
        KC.Q,    KC.W,     KC.E,     KC.R,      KC.T,      KC.Y,     KC.U,    KC.I,    KC.O,     KC.P,
        KC.A,    KC.S,     KC.D,     KC.F,      KC.G,      KC.H,     KC.J,    KC.K,    KC.L,     ______,
        KC.LSFT, KC.Z,     KC.X,     KC.C,      KC.V,      KC.B,     KC.N,    KC.M,    KC_THTA,  KC.ENT,
        KC.LALT,  DIA_EN,   SEC_EN,   KC.TAB,    KC.SPC,    ______,   KC.EQL,  KC.BSPC, ______,   ______,
    ],
    [ # Layer 2 (2nd)
        ______,  MOUSE_TG, SEC_EN,   KC.ESC,  KC.UP,   KC.RIGHT, KC.LCBR, KC.RCBR, KC.LBRC,  KC.RBRC,
        KC.F1,   KC.F5,    KC.LCTRL, ______,  KC.LEFT, KC.DOWN,  KC_INT,  KC.N8,   KC.N9,    KC_SQRT,
        KC.F2,   KC.F6,    KC.DEL,   KC.LGUI, KC.ENT,  ______,   KC_SUM,  KC.N5,   KC.N6,    KC.MINUS,
        KC.F3,   KC.F7,    KC_EX,    ______,  ______,  ______,   KC.N1,   KC.N2,   KC.N3,    KC.PLUS,
        KC.F4,   KC.F8,    KC_SIN,   KC_COS,  KC_TAN,  KC_PI,    KC.LABK, KC.RABK, KC.MINUS, KC.ENT,
        KC.Q,    KC.W,     KC.E,     KC.R,    KC.T,    KC.Y,     KC.U,    KC.I,    KC.O,     KC.P,
        KC.A,    KC.S,     KC.D,     KC.F,    KC.G,    KC.H,     KC_INF,  KC.PIPE, KC.QUOTE, ______,
        KC.CAPS, KC.CAPS,  KC.X,     KC.C,    KC.V,    KC.B,     KC.N,    KC.SCLN, KC.COLN,  KC.ENT,
        KC_PWR,  DIA_EN,   SEC_EN,   KC.TAB,  KC.SPC,  ______,   KC.BSLS, KC.INS,  ______,   ______,
    ],
    [ # Layer 3 (<>)
        ______,  MOUSE_EN, SEC_EN,   KC.ESC,  KC.VOLU, KC.RIGHT, KC.LPRN, KC.RPRN, KC.COMMA, KC.SLASH,
        KC.F1,   KC.F5,    KC.LCTRL, ______,  KC.LEFT, KC.VOLD,  KC.N7,   KC.N8,   KC.N9,    KC.ASTERISK,
        KC.F2,   KC.F6,    KC.DEL,   KC.LGUI, KC.ENT,  ______,   KC.N4,   KC.N5,   KC.N6,    KC.BRID,
        KC.F3,   KC.F7,    KC_LN,    ______,  ______,  ______,   KC.N1,   KC.N2,   KC.N3,    KC.BRIU,
        KC.F4,   KC.F8,    KC_SIN,   KC_COS,  KC_TAN,  KC.CIRC,  KC.N0,   KC.DOT,  KC.MINUS, KC.ENT,
        KC.HOME, KC.W,     KC_NXT,   KC.R,    KC.T,    KC.Y,     KC.U,    KC.I,    KC.O,     KC.P,
        KC.A,    KC.S,     KC.D,     KC.F,    KC.G,    KC.H,     KC.J,    KC.K,    KC.L,     ______,
        KC.LSFT, KC.Z,     KC.X,     KC.C,    KC.V,    KC.B,     KC.N,    KC.M,    KC_THTA,  KC.ENT,
        KC.LALT,  DIA_EN,   SEC_EN,   KC.TAB,  KC.SPC,  ______,   KC.EQL,  KC.DEL,  ______,   ______,
    ]
]

if __name__ == '__main__':
    keyboard.go()

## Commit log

2023-05-19 import of files and initial documentation
    [ti92.kicad_pcb, ti92.kicad_sch, ti92_back_plate.scad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]
2023-05-20 updating keyboard firmware
    Working on issues/1 ; Toggle for mouse functions. Adding ALT key on power button for normal layers.
    [code.py]
